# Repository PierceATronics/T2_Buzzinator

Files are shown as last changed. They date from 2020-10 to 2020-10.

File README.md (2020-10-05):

# T2_Buzzinator
T2 Buzzinator - Programmable Timed Buzzer

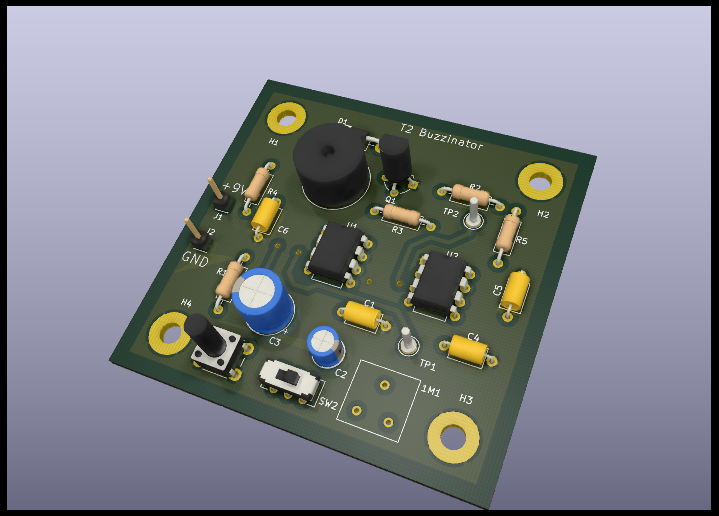
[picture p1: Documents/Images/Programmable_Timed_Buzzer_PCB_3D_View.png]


The T2 Buzzinator is an adjustable timed buzzer circuit emitting noise from a magnetic transducer buzzer for a programmable duration of time. The buzz time duration is programmed simply by a potentiometer and swtich.  The T2 Buzzinator is built around two 555 Timer ICs and other discrete components.

This repo contains the KiCAD schematic and PCB design of the Buzzinator, as well as other supporting documents (Bill of Materials (BOM), LTSpice simulation, etc.)

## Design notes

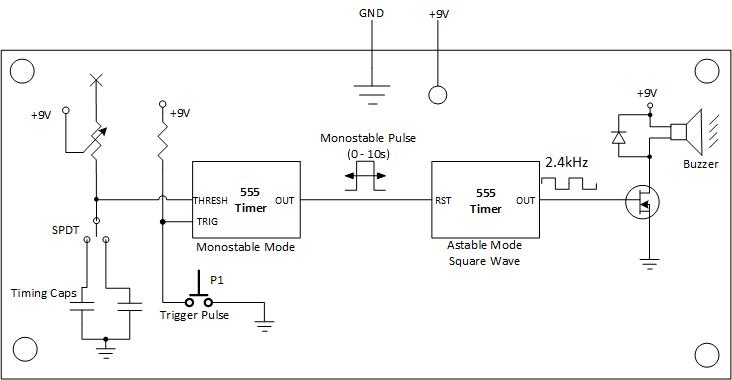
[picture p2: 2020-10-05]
Documents/System_Block_Diagram.jpg

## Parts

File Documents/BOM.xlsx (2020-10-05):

Quantity | Description | MFG P/N | DigiKey | Cost (1 pc) | Ext
2 | IC - Timer, LM555 | LM555CN/NOPB | LM555CNNS/NOPB-ND | $1.14 | $2.28
1 | Buzzer, CEM-1212 | CEM-1212S | 102-1156-ND | $0.86 | $0.86
1 | N-Channel MOSFET, 2N7000 | 2N7000 | 2N7000FS-ND | $0.36 | $0.36
1 | Tactile Switch SPST | 1825910-6 | 450-1650-ND | $0.10 | $0.10
1 | SWITCH SLIDE SPDT 200MA 30V | EG1218 | EG1903-ND | $1.30 | $1.30
1 | Linear POT, 1M Ohm | 3310Y-001-105L | 3310Y-001-105L-ND | $3.10 | $3.10
1 | Res, 1/4W, 5%, 100k Ohm | CF14JT100K | CF14JT100KCT-ND | $0.10 | $0.10
1 | Res, 1/4W, 1%, 160 Ohm | S160CATR | S160CATR-ND | $0.10 | $0.10
1 | Res, 1/4W, 1%, 2.2k Ohm | RNMF14FAD2K20 | RNMF14FAD2K20CT-ND | $0.10 | $0.10
1 | Res, 1/4W, 5% 100 Ohm | CF14JT100R | CF14JT100RCT-ND | $0.10 | $0.10
1 | Diode, 1N4001 | 1N4001-G | 641-1310-1-ND | $0.10 | $0.10
4 | Cap, Ceramic, 0.1uF | C420C104K5R5TA7200 | 399-4491-1-ND | $0.24 | $0.96
1 | Cap, Electrolytic, 10uF | UKL1C100KDD1TD | 493-14344-1-ND | $0.30 | $0.30
2 | DIP 8 Pos Socket Connection | A 08-LC-TT | AE9986-ND | $0.18 | $0.36
1 | Cap, Electrolytic, 100uF | UKL1C101KPDANA | 493-13396-ND | $0.50 | $0.50
 |  |  |  | Total | $10.62

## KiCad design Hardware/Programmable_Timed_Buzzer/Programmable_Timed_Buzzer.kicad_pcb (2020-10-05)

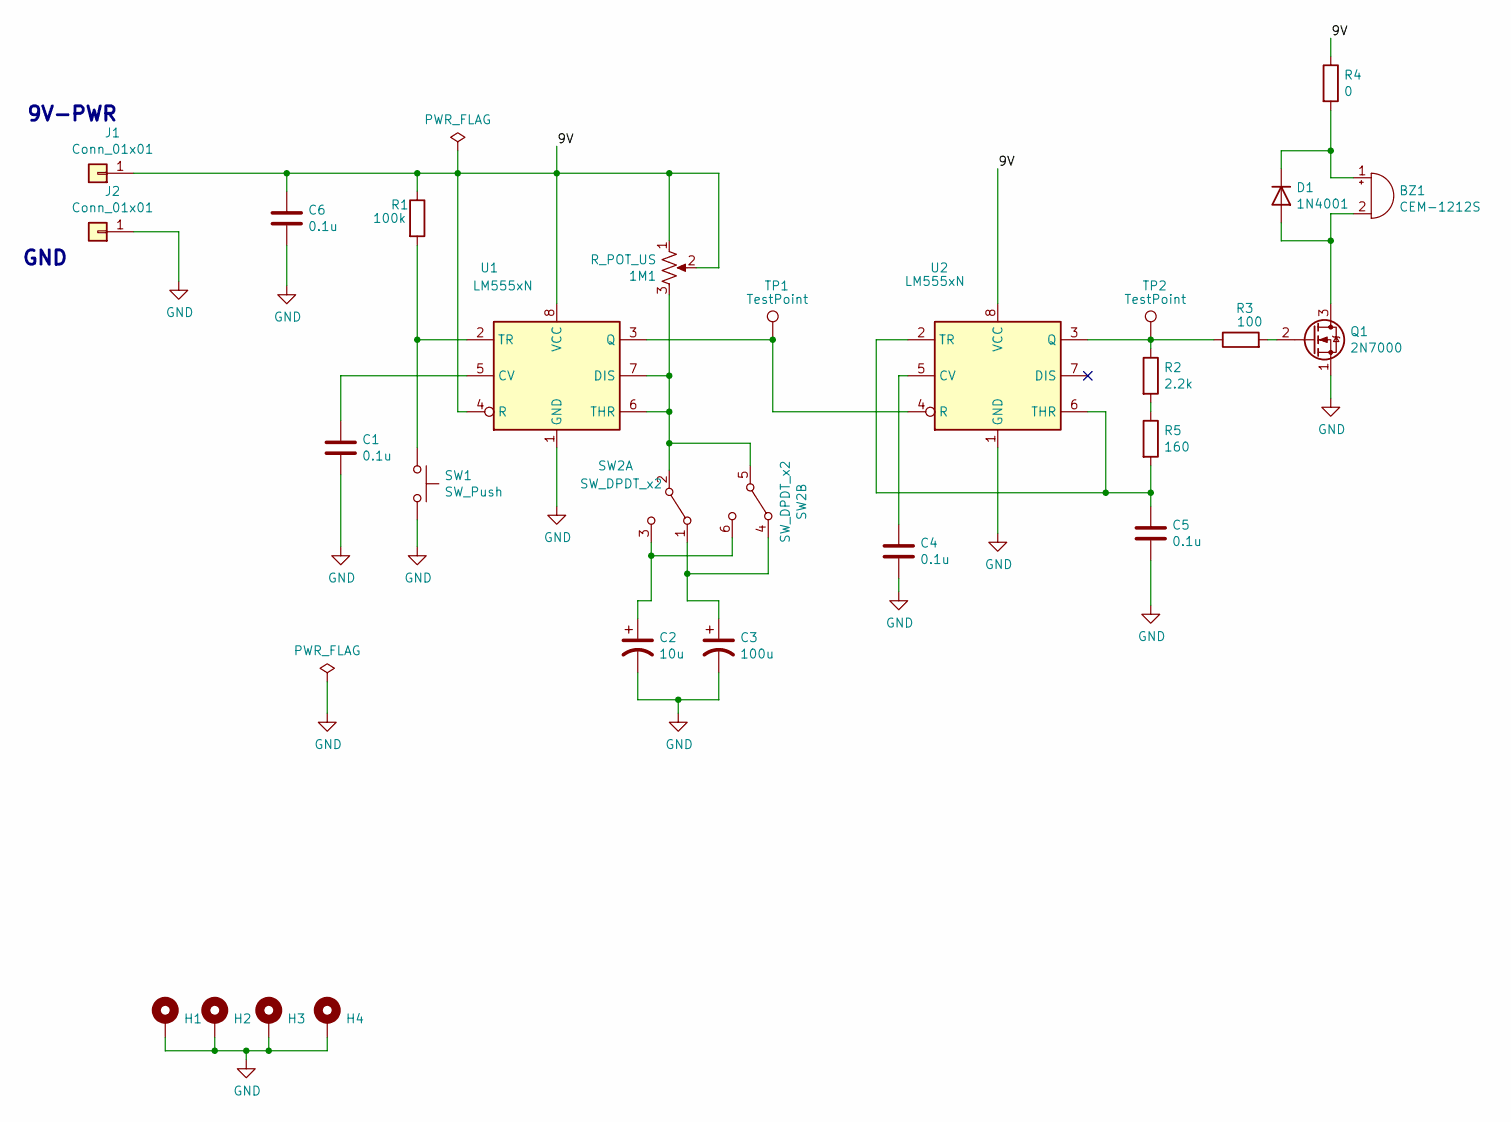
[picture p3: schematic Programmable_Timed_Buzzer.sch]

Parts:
1M1: R_POT_US; Potentiometer_Bourns_3386F_Vertical
BZ1: CEM-1212S; MagneticBuzzer_ProSignal_ABT-410-RC
C1, C4, C5, C6: 0.1u; C_Axial_L5.1mm_D3.1mm_P7.50mm_Horizontal
C2: 10u; CP_Radial_D5.0mm_P2.50mm
C3: 100u; CP_Radial_D8.0mm_P3.50mm
D1: 1N4001; D_DO-41_SOD81_P10.16mm_Horizontal
H1, H2, H3, H4: MountingHole_Pad; MountingHole_3.7mm_Pad
J1, J2: Conn_01x01; PinHeader_1x01_P2.54mm_Vertical
Q1: 2N7000; TO-92L_Wide
R1: 100k; R_Axial_DIN0207_L6.3mm_D2.5mm_P10.16mm_Horizontal
R2: 2.2k; R_Axial_DIN0207_L6.3mm_D2.5mm_P10.16mm_Horizontal
R3: 100; R_Axial_DIN0207_L6.3mm_D2.5mm_P10.16mm_Horizontal
R4: 0; R_Axial_DIN0207_L6.3mm_D2.5mm_P10.16mm_Horizontal
R5: 160; R_Axial_DIN0207_L6.3mm_D2.5mm_P10.16mm_Horizontal
SW1: SW_Push; SW_PUSH_6mm_H13mm
SW2: SW_DPDT_x2; SW_CuK_JS202011CQN_DPDT_Straight
TP1, TP2: TestPoint; Pin_D1.3mm_L11.0mm
U1, U2: LM555xN; DIP-8_W7.62mm

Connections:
/9V: 1M1.1, 1M1.2, C6.1, J1.1, R1.1, R4.1, U1.4 (R), U1.8 (VCC), U2.8 (VCC)
GND: C1.2, C2.2, C3.2, C4.2, C5.2, C6.2, H1.1, H2.1, H3.1, H4.1, J2.1, Q1.1 (S), SW1.2, U1.1 (GND), U2.1 (GND)
unnamed: 1M1.3, SW2.2 (B), SW2.5 (B), U1.6 (THR), U1.7 (DIS)
unnamed: BZ1.1 (-), D1.1 (K), R4.2
unnamed: BZ1.2 (+), D1.2 (A), Q1.3 (D)
unnamed: C1.1, U1.5 (CV)
unnamed: C2.1, SW2.3 (C), SW2.6 (C)
unnamed: C3.1, SW2.1 (A), SW2.4 (A)
unnamed: C4.1, U2.5 (CV)
unnamed: C5.1, R5.2, U2.2 (TR), U2.6 (THR)
unnamed: Q1.2 (G), R3.2
unnamed: R1.2, SW1.1, U1.2 (TR)
unnamed: R2.1, R3.1, TP2.1, U2.3 (Q)
unnamed: R2.2, R5.1
unnamed: TP1.1, U1.3 (Q), U2.4 (R)

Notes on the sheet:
9V-PWR
GND

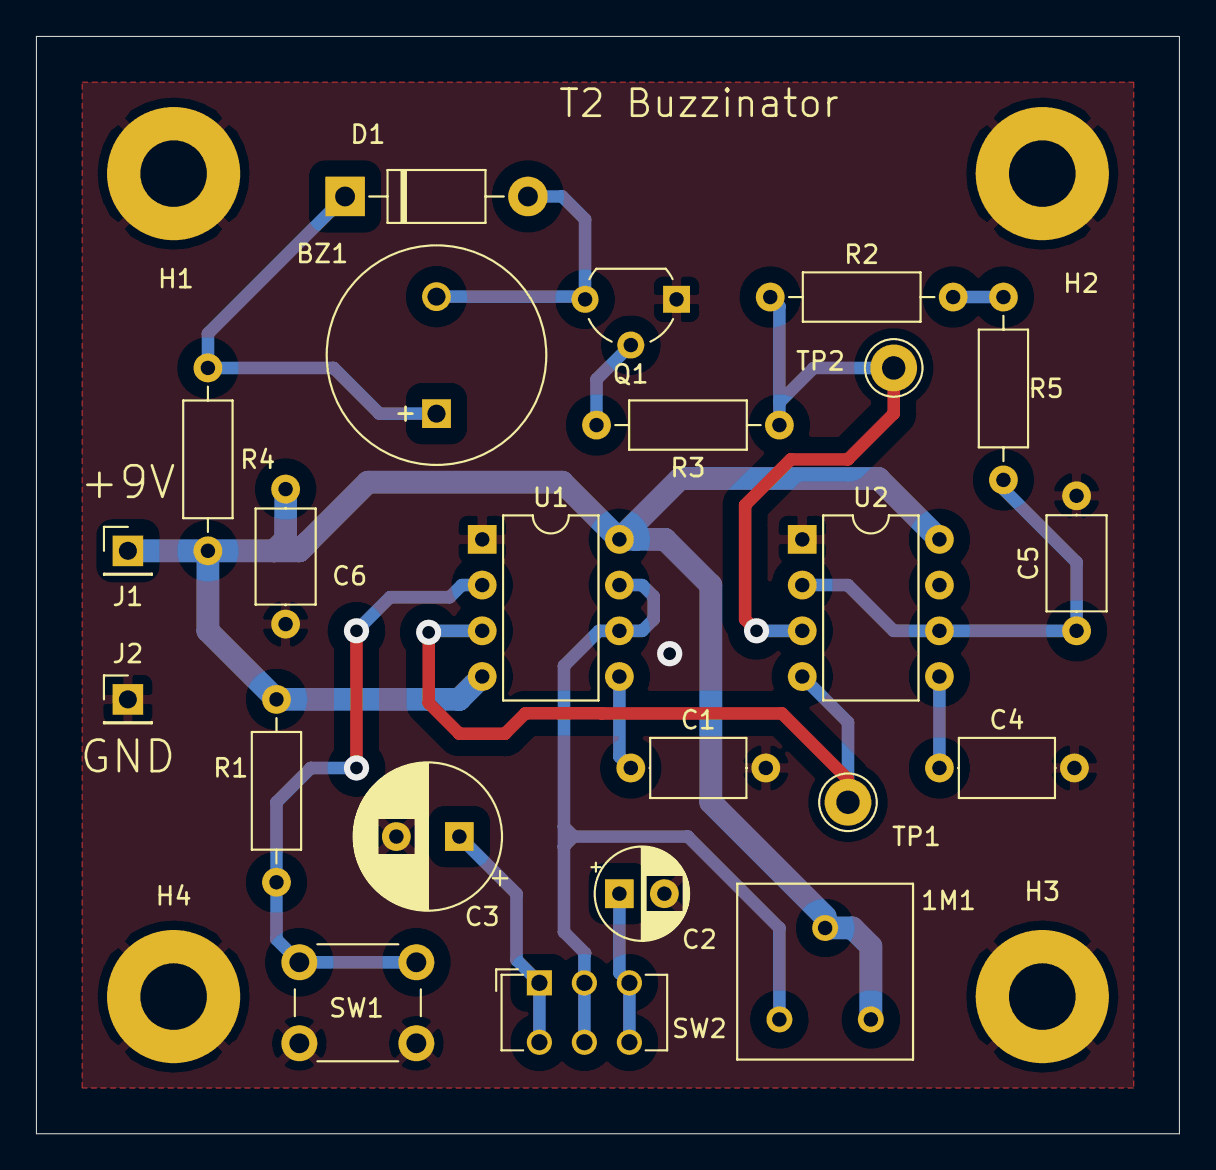
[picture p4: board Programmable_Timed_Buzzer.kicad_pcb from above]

Board: 2 copper layers, 63.5 x 61.0 mm, 27 parts (0 on the bottom side), 15 nets.
